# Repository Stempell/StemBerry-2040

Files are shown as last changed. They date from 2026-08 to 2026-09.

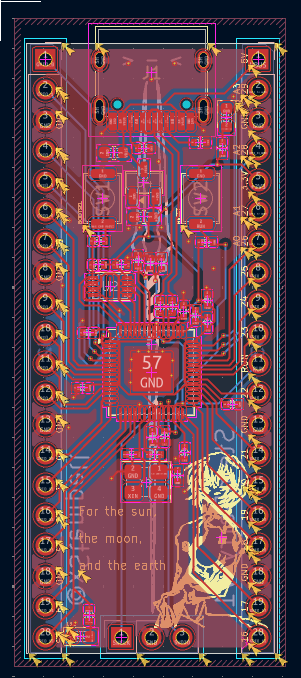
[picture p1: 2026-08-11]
Photos/Zrzut ekranu 2026-08-11 124044.png

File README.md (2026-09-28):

# StemBerry-2040
A RP2040 devboard! Im doing it for Hack Club's Macondo program. It features two buttons for reset and bootsel and two onboard led's (one for power and one is hooked up to pin15), and also a cool evangelion-themed silkscreen art!
It plugs in to breadboards an female headers just like a standard pi pico.
I made this project to learn about making microcontrollers and more advanced pcb's and to have some microcontrollers for personal use. This project taught me a lot and it was also my first time working with restricted space on the board, so every trace and component placement had to be well thought.

Zrzut ekranu 2026-08-11 022354

Zrzut ekranu 2026-08-11 022414

Zrzut ekranu 2026-08-11 125254

The button on the left enters into BOOTSEL mode. The one on the right resets the board.
To upload code press the BOOTSEL button while booting up the board. It will then appear as a USB device on your pc, so you can drop the code in.

## Schematic

Zrzut ekranu 2026-08-11 124234

## Pcb
Zrzut ekranu 2026-08-11 131834

The dimensions are 21 x 51mm

## Bill of materials

| Component | Qty / board | Order qty | Ext. price | JLCPCB part |
|---|---|---|---|---|
| RP2040 | 1 | 5 | $4.94 | [C2040](https://jlcpcb.com/partdetail/C2040) |
| W25Q16JVUXIQ (flash) | 1 | 5 | $8.02 | [C2843335](https://jlcpcb.com/partdetail/C2843335) |
| XC6206P332MR-G (3.3V LDO) | 1 | 5 | $0.66 | [C5446](https://jlcpcb.com/partdetail/C5446) |
| 12MHz crystal | 1 | 5 | $0.47 | [C9002](https://jlcpcb.com/partdetail/C9002) |
| USB_C_Receptacle_USB2.0_14P | 1 | 5 | $0.92 | [C165948](https://jlcpcb.com/partdetail/C165948) |
| SW_Push | 2 | 10 | $0.55 | [C720477](https://jlcpcb.com/partdetail/C720477) |
| 100nF | 12 | 60 | $0.32 | [C1525](https://jlcpcb.com/partdetail/C1525) |
| 1uF | 2 | 10 | $0.16 | [C52923](https://jlcpcb.com/partdetail/C52923) |
| 10uF | 2 | 10 | $0.39 | [C19702](https://jlcpcb.com/partdetail/C19702) |
| 33pF | 2 | 10 | $0.07 | [C1562](https://jlcpcb.com/partdetail/C1562) |
| 5.1K | 2 | 10 | $0.06 | [C25905](https://jlcpcb.com/partdetail/C25905) |
| 27 | 2 | 20 | $0.03 | [C25156](https://jlcpcb.com/partdetail/C25156) |
| 1K | 2 | 10 | $0.07 | [C11702](https://jlcpcb.com/partdetail/C11702) |
| 10K | 1 | 5 | $0.04 | [C25744](https://jlcpcb.com/partdetail/C25744) |
| 330 | 1 | 5 | $0.04 | [C25104](https://jlcpcb.com/partdetail/C25104) |
| 470 | 1 | 5 | $0.03 | [C25117](https://jlcpcb.com/partdetail/C25117) |
| 100K | 1 | 5 | $0.04 | [C25741](https://jlcpcb.com/partdetail/C25741) |
| LED (0603) | 1 | 5 | $0.04 | [C2286](https://jlcpcb.com/partdetail/C2286) |
| LED (0805) | 1 | 5 | $0.08 | [C2297](https://jlcpcb.com/partdetail/C2297) |
| **Total** | | | **$16.93** | |

Additional charges and assembly costs rung me up $26.13
You will also need to hand solder two 1x20 male to male pin headers like these ones for like $3.17:

https://pl.aliexpress.com/item/1005007486600604.html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

Total cost: $44.43

If you wish to learn how to make a devboard like this one yourself, or any other devboard similar to this one check out the guide i used:

https://macondo.hackclub.com/docs/build-a-devboard

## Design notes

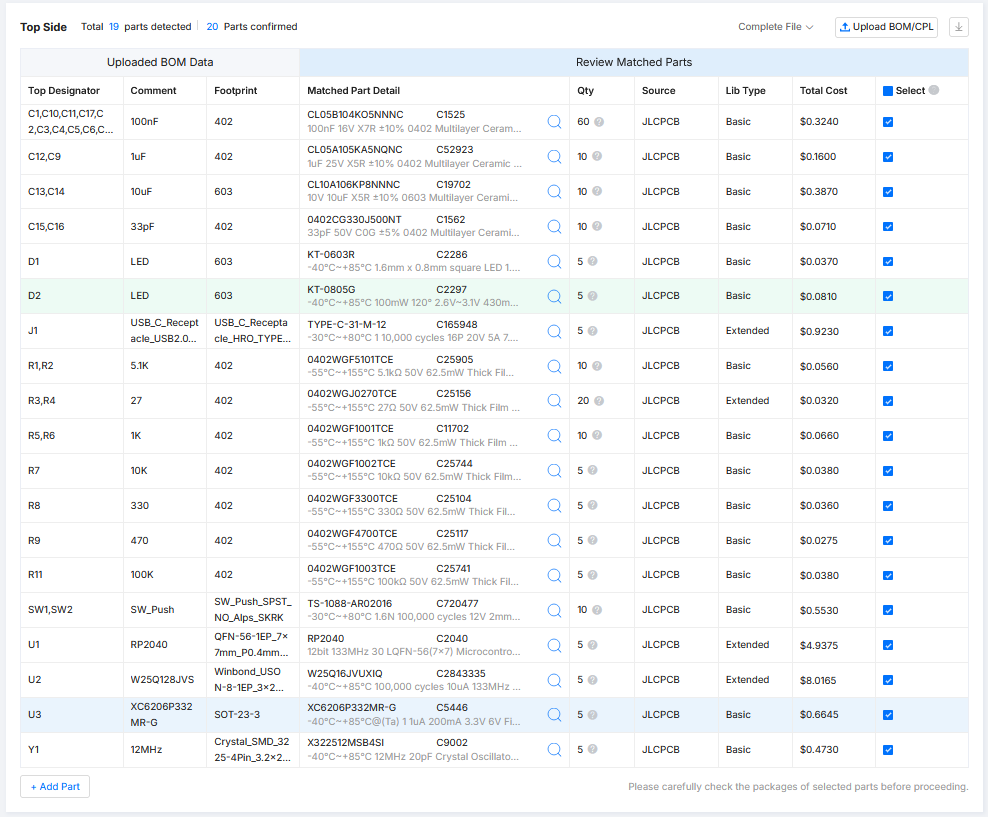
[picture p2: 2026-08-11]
Photos/Zrzut ekranu 2026-08-11 144218.png

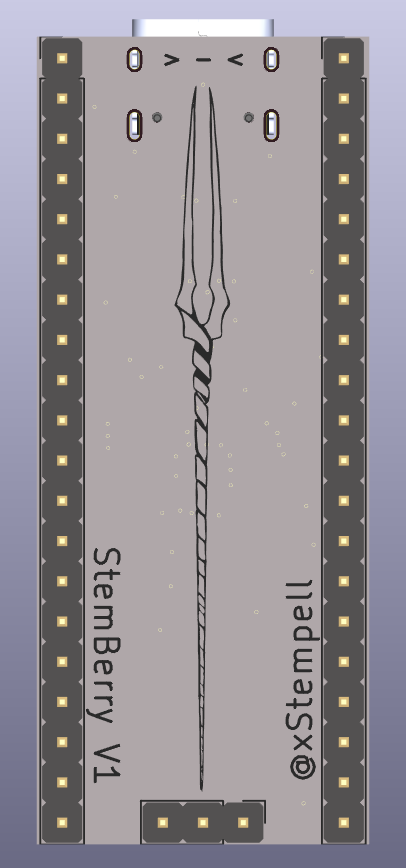
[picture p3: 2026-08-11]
Photos/Zrzut ekranu 2026-08-11 022414.png

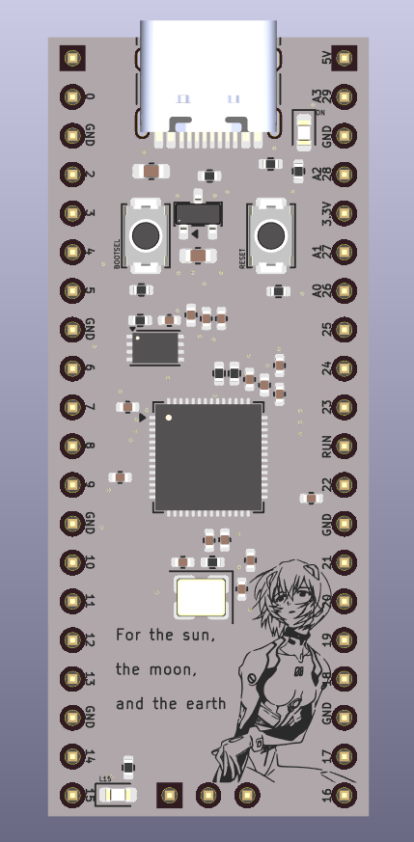
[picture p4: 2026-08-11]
Photos/Zrzut ekranu 2026-08-11 022354.png

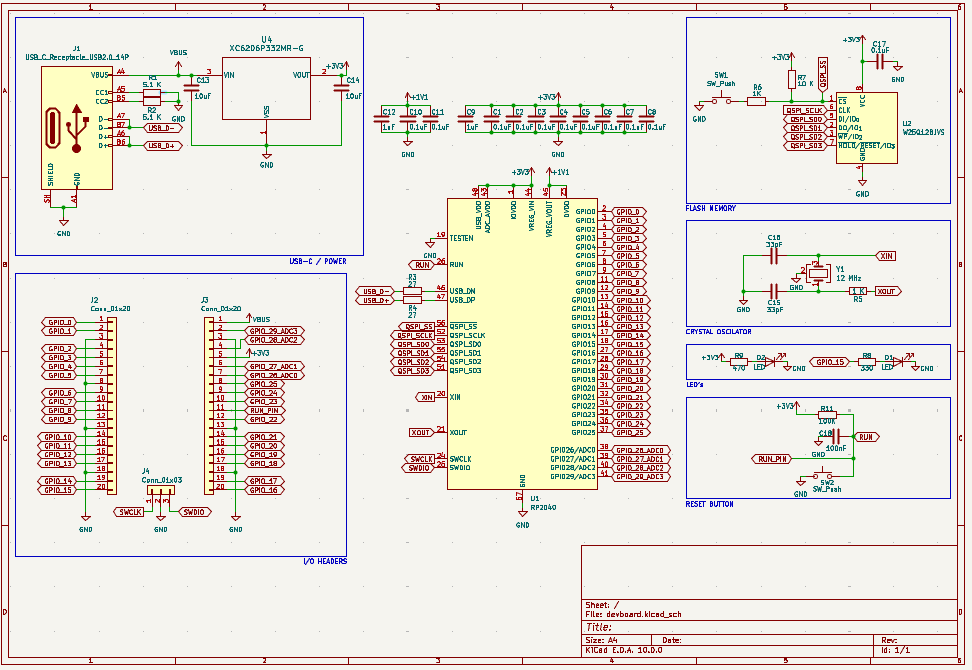
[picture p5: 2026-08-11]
Photos/Zrzut ekranu 2026-08-11 124234.png

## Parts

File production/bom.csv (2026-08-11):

Designator | Footprint | Quantity | Value | LCSC Part #
C1, C10, C11, C17, C2, C3, C4, C5, C6, C7, C8 | 0402 | 11 | 0.1uF
C12, C9 | 0402 | 2 | 1uF
C13, C14 | 0603 | 2 | 10uF
C15, C16 | 0402 | 2 | 33pF
C18 | 0402 | 1 | 100nF
D1, D2 | 0603 | 2 | LED
J1 | USB_C_Receptacle_HRO_TYPE-C-31-M-12 | 1 | USB_C_Receptacle_USB2.0_14P
J2, J3 | PinHeader_1x20_P2.54mm_Vertical | 2 | Conn_01x20
J4 | PinHeader_1x03_P2.54mm_Vertical | 1 | Conn_01x03
R1, R2 | 0402 | 2 | 5.1 K
R11 | 0402 | 1 | 100K
R3, R4 | 0402 | 2 | 27
R5 | 0402 | 1 | 1 K
R6 | 0402 | 1 | 1K
R7 | 0402 | 1 | 10 K
R8 | 0402 | 1 | 330
R9 | 0402 | 1 | 470
SW1, SW2 | SW_Push_SPST_NO_Alps_SKRK | 2 | SW_Push
U1 | QFN-56-1EP_7x7mm_P0.4mm_EP3.2x3.2mm | 1 | RP2040
U2 | Winbond_USON-8-1EP_3x2mm_P0.5mm_EP0.2x1.6mm | 1 | W25Q128JVS
U4 | SOT-23-3 | 1 | XC6206P332MR-G
Y1 | Crystal_SMD_3225-4Pin_3.2x2.5mm | 1 | 12 MHz

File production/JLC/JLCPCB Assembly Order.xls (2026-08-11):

JLCPCB BOM Tool - BOM Matching
BOM name：JLCPCB Assembly Order-JLCPCB Assembly Order.xlsx |  |  | Download Time：2026-08-11 21:29:07 |  |  |  | * Our matching results are updated in real-time, but stock and prices may change. If it's been over 24 hours, please re-match before placing your order.
PCB Assembled Qty：5 |  |  | Est. Total Price：8.9045
Your BOM |  |  |  | Matched Parts |  |  |  |  |  |  | Order Information
Designator | Comment | Footprint | JLCPCB Part # | Matches | Part # | Manufacturer | Footprint | Description | Category | Warning | JLCPCB Part # | Product link | Lib Type | Qty | Source | Total Price ($)
C1,C10,C11,C17,C2,C3,C4,C5,C6,C7,C8,C18 | 100nF | 0402 |  | Select by System | CL05B104KO5NNNC | Samsung Electro-Mechanics | 0402 | 100nF 16V X7R ±10% 0402 Multilayer Ceramic Capacitors MLCC - SMD/SMT ROHS | Multilayer Ceramic Capacitors MLCC - SMD/SMT |  | C1525 | https://jlcpcb.com/partdetail/1877-CL05B104KO5NNNC/C1525 | Basic | 60 | 60 JLCPCB | 0.324
C12,C9 | 1uF | 0402 |  | Select by System | CL05A105KA5NQNC | Samsung Electro-Mechanics | 0402 | 1uF 25V X5R ±10% 0402 Multilayer Ceramic Capacitors MLCC - SMD/SMT ROHS | Multilayer Ceramic Capacitors MLCC - SMD/SMT |  | C52923 | https://jlcpcb.com/partdetail/53938-CL05A105KA5NQNC/C52923 | Basic | 10 | 10 JLCPCB | 0.16
C13,C14 | 10uF | 0603 |  | Select by System | CL10A106KP8NNNC | Samsung Electro-Mechanics | 0603 | 10V 10uF X5R ±10% 0603 Multilayer Ceramic Capacitors MLCC - SMD/SMT ROHS | Multilayer Ceramic Capacitors MLCC - SMD/SMT |  | C19702 | https://jlcpcb.com/partdetail/20411-CL10A106KP8NNNC/C19702 | Basic | 10 | 10 JLCPCB | 0.387
C15,C16 | 33pF | 0402 |  | Select by System | 0402CG330J500NT | FH (Guangdong Fenghua Advanced Tech) | 0402 | 33pF 50V C0G ±5% 0402 Multilayer Ceramic Capacitors MLCC - SMD/SMT ROHS | Multilayer Ceramic Capacitors MLCC - SMD/SMT |  | C1562 | https://jlcpcb.com/partdetail/1914-0402CG330J500NT/C1562 | Basic | 10 | 10 JLCPCB | 0.071
D1 | LED | 0603 |  | Select by System | KT-0603R | Hubei KENTO Elec | 0603 | -40℃~+85℃ 1.6mm x 0.8mm square LED 1.8V~2.4V 120° 20mA 300mcd 40mW 615nm~630nm 645nm Discrete Diode Red Water Clear 0603 LED Indication - Discrete ROHS | LED Indication - Discrete |  | C2286 | https://jlcpcb.com/partdetail/Hubei_KENTOElec-KT0603R/C2286 | Basic | 5 | 5 JLCPCB | 0.037
D2 | LED | 0805 |  | Select by System | KT-0805G | Hubei KENTO Elec | 0805 | -40℃~+85℃ 100mW 120° 2.6V~3.1V 430mcd 513nm~528nm 525nm 5mA Discrete Diode Emerald Green Water Clear 0805 LED Indication - Discrete ROHS | LED Indication - Discrete |  | C2297 | https://jlcpcb.com/partdetail/Hubei_KENTOElec-KT0805G/C2297 | Basic | 5 | 5 JLCPCB | 0.081
J1 | USB_C_Receptacle_USB2.0_14P | SMD |  | Select by System | TYPE-C-31-M-12 | Korean Hroparts Elec | SMD | -30℃~+80℃ 1 10,000 cycles 16P 20V 5A 7.35mm Female Surface Mount, Right Angle Type-C SMD USB Connectors ROHS | USB Connectors |  | C165948 | https://jlcpcb.com/partdetail/Korean_HropartsElec-TYPE_C_31_M12/C165948 | Extended | 5 | 5 JLCPCB | 0.923
R1,R2 | 5.1K | 0402 |  | Select by System | 0402WGF5101TCE | UNI-ROYAL(Uniroyal Elec) | 0402 | -55℃~+155℃ 5.1kΩ 50V 62.5mW Thick Film Resistor ±1% ±100ppm/℃ 0402 Chip Resistor - Surface Mount ROHS | Chip Resistor - Surface Mount |  | C25905 | https://jlcpcb.com/partdetail/26648-0402WGF5101TCE/C25905 | Basic | 10 | 10 JLCPCB | 0.056
R3,R4 | 27 | 0402 |  | Select by System | 0402WGJ0270TCE | UNI-ROYAL(Uniroyal Elec) | 0402 | -55℃~+155℃ 27Ω 50V 62.5mW Thick Film Resistor ±100ppm/℃ ±5% 0402 Chip Resistor - Surface Mount ROHS | Chip Resistor - Surface Mount |  | C25156 | https://jlcpcb.com/partdetail/25899-0402WGJ0270TCE/C25156 | Extended | 20 | 20 JLCPCB | 0.032
R5,R6 | 1K | 0402 |  | Select by System | 0402WGF1001TCE | UNI-ROYAL(Uniroyal Elec) | 0402 | -55℃~+155℃ 1kΩ 50V 62.5mW Thick Film Resistor ±1% ±100ppm/℃ 0402 Chip Resistor - Surface Mount ROHS | Chip Resistor - Surface Mount |  | C11702 | https://jlcpcb.com/partdetail/12256-0402WGF1001TCE/C11702 | Basic | 10 | 10 JLCPCB | 0.066
R7 | 10K | 0402 |  | Select by System | 0402WGF1002TCE | UNI-ROYAL(Uniroyal Elec) | 0402 | -55℃~+155℃ 10kΩ 50V 62.5mW Thick Film Resistor ±1% ±100ppm/℃ 0402 Chip Resistor - Surface Mount ROHS | Chip Resistor - Surface Mount |  | C25744 | https://jlcpcb.com/partdetail/26487-0402WGF1002TCE/C25744 | Basic | 5 | 5 JLCPCB | 0.038
R8 | 330 | 0402 |  | Select by System | 0402WGF3300TCE | UNI-ROYAL(Uniroyal Elec) | 0402 | -55℃~+155℃ 330Ω 50V 62.5mW Thick Film Resistor ±1% ±100ppm/℃ 0402 Chip Resistor - Surface Mount ROHS | Chip Resistor - Surface Mount |  | C25104 | https://jlcpcb.com/partdetail/25847-0402WGF3300TCE/C25104 | Basic | 5 | 5 JLCPCB | 0.036
R9 | 470 | 0402 |  | Select by System | 0402WGF4700TCE | UNI-ROYAL(Uniroyal Elec) | 0402 | -55℃~+155℃ 470Ω 50V 62.5mW Thick Film Resistor ±1% ±100ppm/℃ 0402 Chip Resistor - Surface Mount ROHS | Chip Resistor - Surface Mount |  | C25117 | https://jlcpcb.com/partdetail/25860-0402WGF4700TCE/C25117 | Basic | 5 | 5 JLCPCB | 0.0275
R11 | 100K | 0402 |  | Select by System | 0402WGF1003TCE | UNI-ROYAL(Uniroyal Elec) | 0402 | -55℃~+155℃ 100kΩ 50V 62.5mW Thick Film Resistor ±1% ±100ppm/℃ 0402 Chip Resistor - Surface Mount ROHS | Chip Resistor - Surface Mount |  | C25741 | https://jlcpcb.com/partdetail/26484-0402WGF1003TCE/C25741 | Basic | 5 | 5 JLCPCB | 0.038
SW1,SW2 | SW_Push | SMD,4x3mm |  | Select by System | TS-1088-AR02016 | XUNPU | SMD,4x3mm | -30℃~+80℃ 1.6N 100,000 cycles 12V 2mm 3.9mm 3mm 50mA Black Round Button SMD(SMT) Tab SPST Surface Mount,Vertical Without Bracket SMD,4x3mm Tactile Switches ROHS | Tactile Switches |  | C720477 | https://jlcpcb.com/partdetail/XUNPU-TS_1088AR02016/C720477 | Basic | 10 | 10 JLCPCB | 0.553
U1 | RP2040 | LQFN-56(7x7) |  | Select by System | RP2040 | Raspberry Pi | LQFN-56(7x7) | 12bit 133MHz 30 LQFN-56(7x7) Microcontrollers (MCU/MPU/SOC) ROHS | Microcontrollers (MCU/MPU/SOC) |  | C2040 | https://jlcpcb.com/partdetail/RaspberryPi-RP2040/C2040 | Extended | 5 | 5 JLCPCB | 4.9375
U2 | W25Q16JVUXIQ | USON-8-EP(2x3) |  | Select by System | W25Q16JVUXIQ | Winbond Elec | USON-8-EP(2x3) | -40℃~+85℃ 100,000 cycles 10uA 133MHz 16Mbit 2.7V~3.6V 20 Years 3ms SPI USON-8-EP(2x3) NOR FLASH ROHS | NOR FLASH |  | C2843335 | https://jlcpcb.com/partdetail/WinbondElec-W25Q16JVUXIQ/C2843335 | Extended | 0 | 0 JLCPCB | 0
U3 | XC6206P332MR-G | SOT-23-3L |  | Select by System | XC6206P332MR-G | Torex Semicon | SOT-23-3L | -40℃~+85℃@(Ta) 1 1uA 200mA 3.3V 6V Fixed Over Current Protection Positive SOT-23-3L Voltage Regulators - Linear, Low Drop Out (LDO) Regulators ROHS | Voltage Regulators - Linear, Low Drop Out (LDO) Regulators |  | C5446 | https://jlcpcb.com/partdetail/TorexSemicon-XC6206P332MRG/C5446 | Basic | 5 | 5 JLCPCB | 0.6645
Y1 | 12MHz | SMD3225-4P |  | Select by System | X322512MSB4SI | YXC Crystal Oscillators | SMD3225-4P | -40℃~+85℃ 12MHz 20pF Crystal Oscillator ±10ppm ±20ppm SMD3225-4P Crystals ROHS | Crystals |  | C9002 | https://jlcpcb.com/partdetail/YXC_CrystalOscillators-X322512MSB4SI/C9002 | Basic | 5 | 5 JLCPCB | 0.473

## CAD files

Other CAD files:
board mode.step

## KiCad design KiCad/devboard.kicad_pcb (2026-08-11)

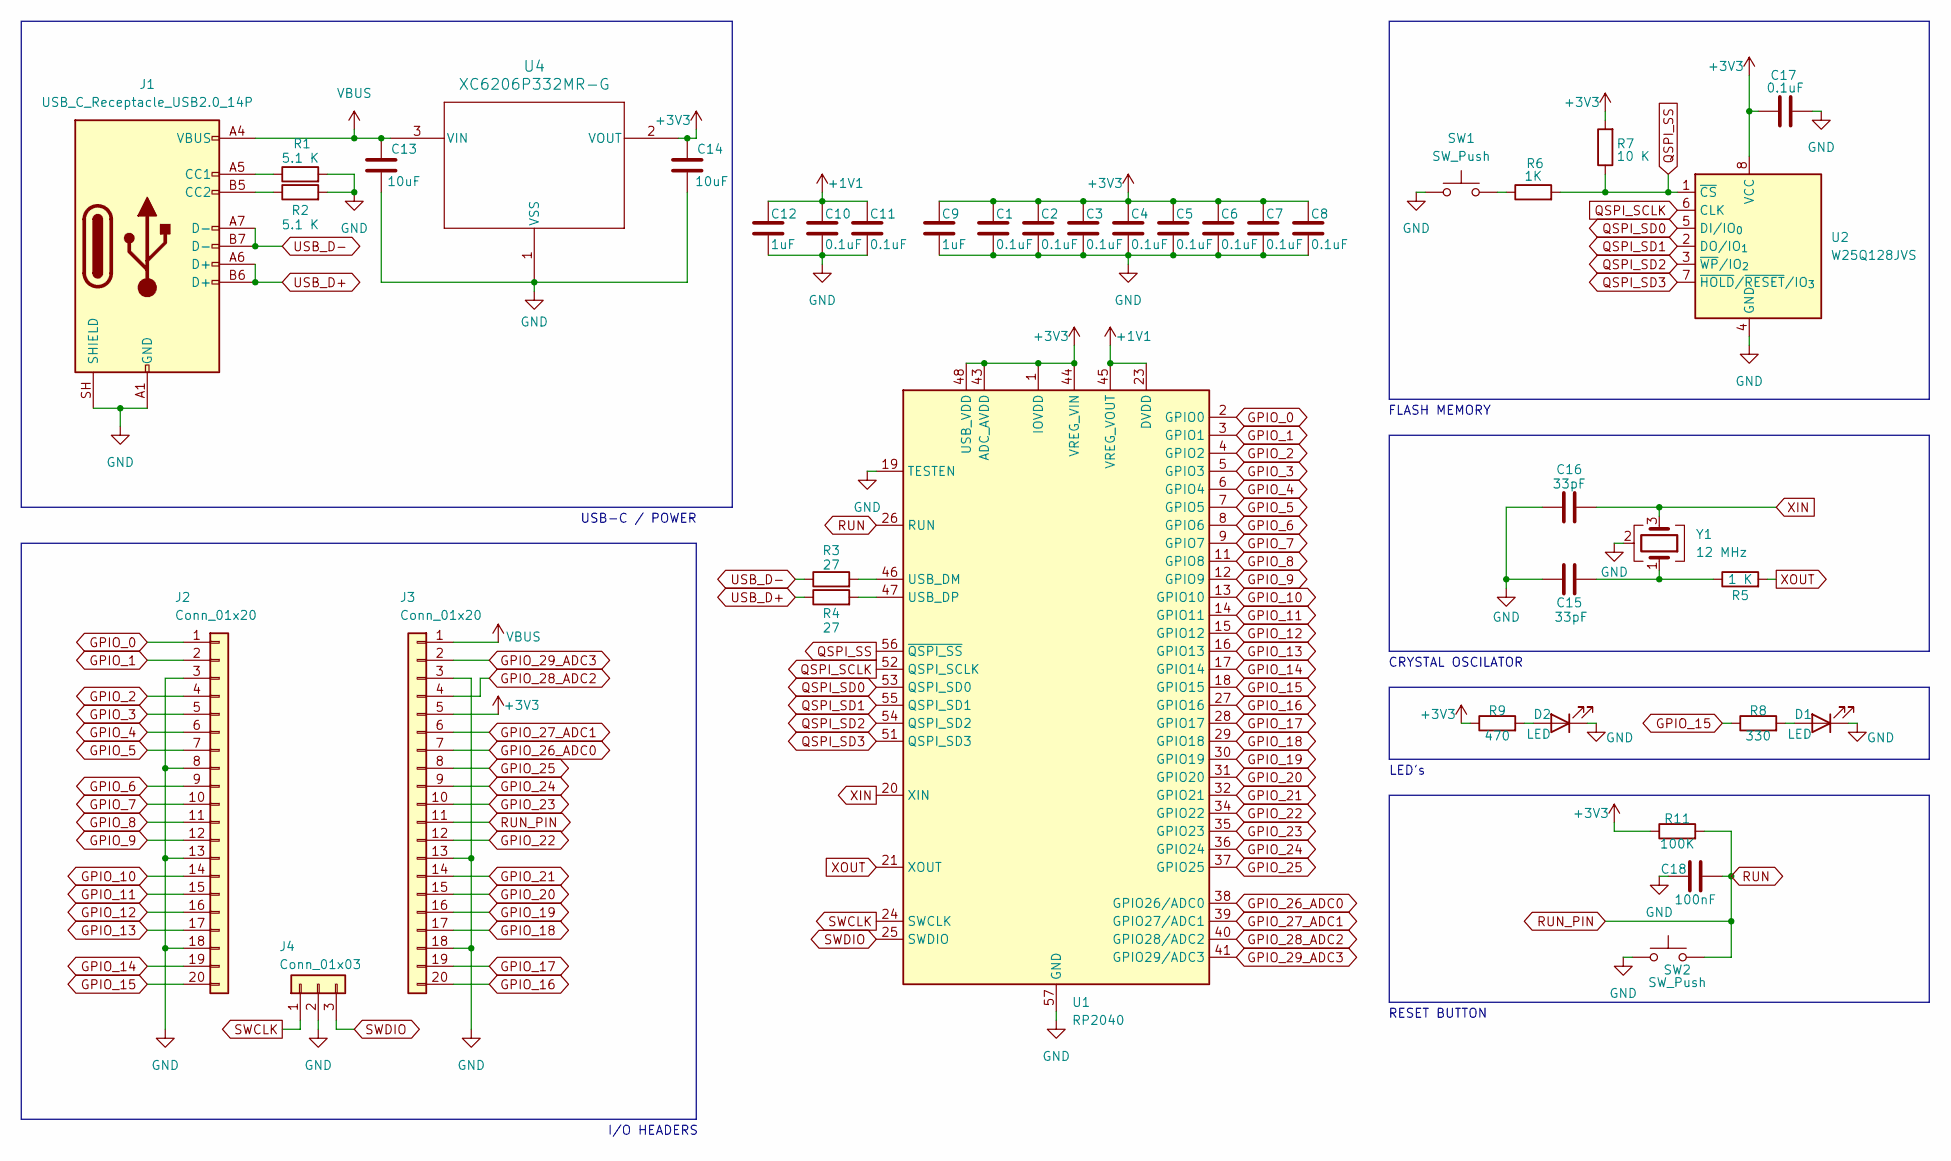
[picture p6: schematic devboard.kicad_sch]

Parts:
C1, C2, C3, C4, C5, C6, C7, C8, C10, C11, C17: 0.1uF; C_0402_1005Metric
C9, C12: 1uF; C_0402_1005Metric
C13, C14: 10uF; C_0603_1608Metric
C15, C16: 33pF; C_0402_1005Metric
C18: 100nF; C_0402_1005Metric
D1, D2: LED; LED_0603_1608Metric
J1: USB_C_Receptacle_USB2.0_14P; USB_C_Receptacle_HRO_TYPE-C-31-M-12
J2, J3: Conn_01x20; PinHeader_1x20_P2.54mm_Vertical
J4: Conn_01x03; PinHeader_1x03_P2.54mm_Vertical
R1, R2: 5.1 K; R_0402_1005Metric
R3, R4: 27; R_0402_1005Metric
R5: 1 K; R_0402_1005Metric
R6: 1K; R_0402_1005Metric
R7: 10 K; R_0402_1005Metric
R8: 330; R_0402_1005Metric
R9: 470; R_0402_1005Metric
R11: 100K; R_0402_1005Metric
SW1, SW2: SW_Push; SW_Push_SPST_NO_Alps_SKRK
U1: RP2040; QFN-56-1EP_7x7mm_P0.4mm_EP3.2x3.2mm
U2: W25Q128JVS; Winbond_USON-8-1EP_3x2mm_P0.5mm_EP0.2x1.6mm
U4: XC6206P332MR-G; SOT-23-3
Y1: 12 MHz; Crystal_SMD_3225-4Pin_3.2x2.5mm

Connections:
+1V1: C10.1, C11.1, C12.1, U1.23 (DVDD), U1.45 (VREG_VOUT), U1.50 (DVDD)
+3V3: C1.1, C2.1, C3.1, C4.1, C5.1, C6.1, C7.1, C8.1, C9.1, C14.1, C17.1, J3.5, R7.2, R9.1, R11.1, U1.1 (IOVDD), U1.10 (IOVDD), U1.22 (IOVDD), U1.33 (IOVDD), U1.42 (IOVDD), U1.43 (ADC_AVDD), U1.44 (VREG_VIN), U1.48 (USB_VDD), U1.49 (IOVDD), U2.8 (VCC), U4.2 (VOUT); also elsewhere on the board
GND: C1.2, C2.2, C3.2, C4.2, C5.2, C6.2, C7.2, C8.2, C9.2, C10.2, C11.2, C12.2, C13.2, C14.2, C15.1, C16.1, C17.2, C18.1, D1.1 (K), D2.1 (K), J1.A1 (GND), J1.A12 (GND), J1.B1 (GND), J1.B12 (GND), J1.SH (SHIELD), J2.3, J2.8, J2.13, J2.18, J3.3, J3.13, J3.18, J4.2, R1.2, R2.2, SW1.1, SW2.1, U1.19 (TESTEN), U1.57 (GND), U2.4 (GND), U4.1 (VSS), Y1.2 (G), Y1.4 (G); also elsewhere on the board
GPIO_0: J2.1, U1.2 (GPIO0)
GPIO_1: J2.2, U1.3 (GPIO1)
GPIO_2: J2.4, U1.4 (GPIO2)
GPIO_3: J2.5, U1.5 (GPIO3)
GPIO_4: J2.6, U1.6 (GPIO4)
GPIO_5: J2.7, U1.7 (GPIO5)
GPIO_6: J2.9, U1.8 (GPIO6)
GPIO_7: J2.10, U1.9 (GPIO7)
GPIO_8: J2.11, U1.11 (GPIO8)
GPIO_9: J2.12, U1.12 (GPIO9)
GPIO_10: J2.14, U1.13 (GPIO10)
GPIO_11: J2.15, U1.14 (GPIO11)
GPIO_12: J2.16, U1.15 (GPIO12)
GPIO_13: J2.17, U1.16 (GPIO13)
GPIO_14: J2.19, U1.17 (GPIO14)
GPIO_15: J2.20, R8.1, U1.18 (GPIO15)
GPIO_16: J3.20, U1.27 (GPIO16)
GPIO_17: J3.19, U1.28 (GPIO17)
GPIO_18: J3.17, U1.29 (GPIO18)
GPIO_19: J3.16, U1.30 (GPIO19)
GPIO_20: J3.15, U1.31 (GPIO20)
GPIO_21: J3.14, U1.32 (GPIO21)
GPIO_22: J3.12, U1.34 (GPIO22)
GPIO_23: J3.10, U1.35 (GPIO23)
GPIO_24: J3.9, U1.36 (GPIO24)
GPIO_25: J3.8, U1.37 (GPIO25)
GPIO_26_ADC0: J3.7, U1.38 (GPIO26/ADC0)
GPIO_27_ADC1: J3.6, U1.39 (GPIO27/ADC1)
GPIO_28_ADC2: J3.4, U1.40 (GPIO28/ADC2)
GPIO_29_ADC3: J3.2, U1.41 (GPIO29/ADC3)
unnamed: C15.2, R5.1, Y1.1
unnamed: D1.2 (A), R8.2
unnamed: D2.2 (A), R9.2
unnamed: J1.A5 (CC1), R1.1
unnamed: J1.B5 (CC2), R2.1
unnamed: R6.1, SW1.2
unnamed: R3.2, U1.46 (USB_DM)
unnamed: R4.2, U1.47 (USB_DP)
QSPI_SCLK: U1.52 (QSPI_SCLK), U2.6 (CLK)
QSPI_SD0: U1.53 (QSPI_SD0), U2.5 (DI/IO_{0})
QSPI_SD1: U1.55 (QSPI_SD1), U2.2 (DO/IO_{1})
QSPI_SD2: U1.54 (QSPI_SD2), U2.3 (~WP/IO_{2})
QSPI_SD3: U1.51 (QSPI_SD3), U2.7 (~HOLD/~RESET/IO_{3})
QSPI_SS: R6.2, R7.1, U1.56 (~QSPI_SS), U2.1 (~CS)
RUN: C18.2, J3.11, R11.2, SW2.2, U1.26 (RUN)
SWCLK: J4.1, U1.24 (SWCLK)
SWDIO: J4.3, U1.25 (SWDIO)
USB_D+: J1.A6 (D+), J1.B6 (D+), R4.1
USB_D-: J1.A7 (D-), J1.B7 (D-), R3.1
VBUS: C13.1, J1.A4 (VBUS), J1.A9 (VBUS), J1.B4 (VBUS), J1.B9 (VBUS), J3.1, U4.3 (VIN); also elsewhere on the board
XIN: C16.2, U1.20 (XIN), Y1.3
XOUT: R5.2, U1.21 (XOUT)

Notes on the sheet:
I/O HEADERS
USB-C / POWER
FLASH MEMORY
LED's
CRYSTAL OSCILATOR
RESET BUTTON

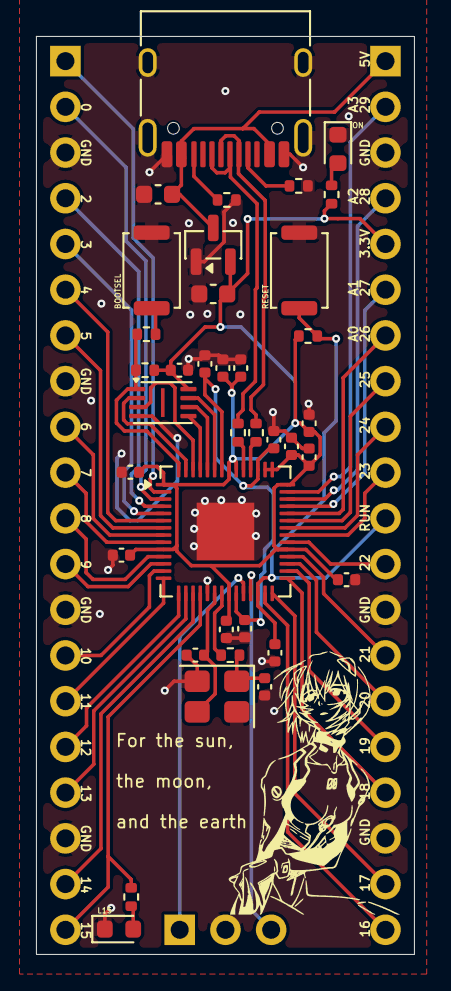
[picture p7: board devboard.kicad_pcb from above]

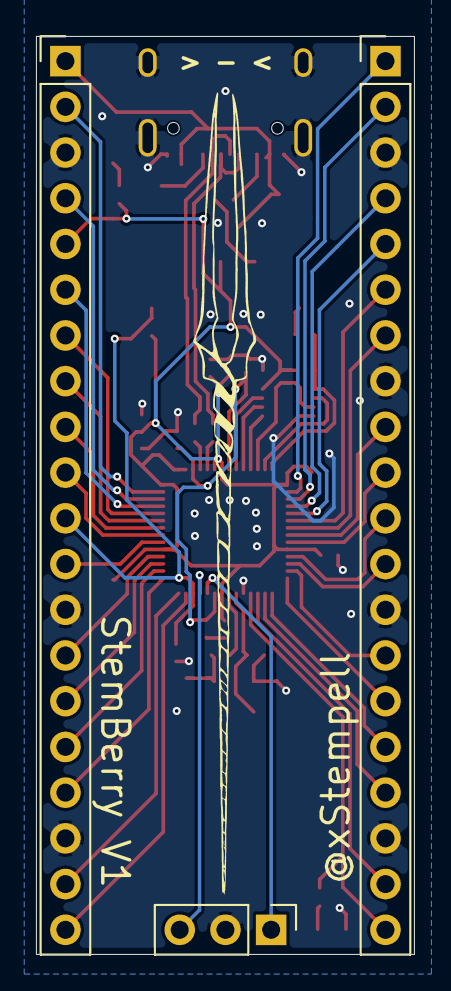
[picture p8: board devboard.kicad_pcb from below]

Board: 2 copper layers, 21.0 x 51.0 mm, 40 parts (3 on the bottom side), 55 nets.

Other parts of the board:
U3: MCP1700x-330xxTT; SOT-23

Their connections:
+3V3: U3.2 (VO); also elsewhere on the board
GND: U3.1 (GND); also elsewhere on the board
VBUS: U3.3 (VI); also elsewhere on the board

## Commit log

2026-07-19 updated KiCad folder
    [bom.csv, designators.csv, devboard.kicad_pcb]
2026-07-19 readme update
    Added an image and description for BOOTSEL mode and reset button.
2026-08-11 switched out the LDO and power LED
    [bom.csv, designators.csv, devboard.kicad_pcb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]
2026-08-11 Revise README with project details and BOM
    Updated project description and added bill of materials with detailed components.
2026-08-11 pcb update
    [JLCPCB Assembly Order.xls, bom.csv, designators.csv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]
2026-08-11 added gerbers
2026-09-28 added step file of the board
    [.step]
